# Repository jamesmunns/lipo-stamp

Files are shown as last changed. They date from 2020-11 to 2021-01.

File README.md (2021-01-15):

# LiPo Power Stamp

This is intended to be a small sized, general purpose LiPo charge controller with power path and a 3v3 regulator. Currently the targeted size is 0.7" by 0.7", or just under 18mm square. It is intended to be used with 3.7V nominal cells.

## Features

* TP4056 Charge Controller
    * 500mA charging current
    * Low voltage trickle charging
* Over/Under-voltage Protection
    * AP9101CK6 + FS8205
    * Disables cell on over/under charge
* Power Path
    * Provides power via USB when connected
    * 500mA max output (USB or Cell)
* Switchable 3v3 Regulator
    * Default off
    * 100mA+ output
* Resettable Polyfuse
    * For high current, direct battery applications (e.g. LEDs)
    * Max 2A continuous output

## Stamp v0.3.0

This is the current version of the board.

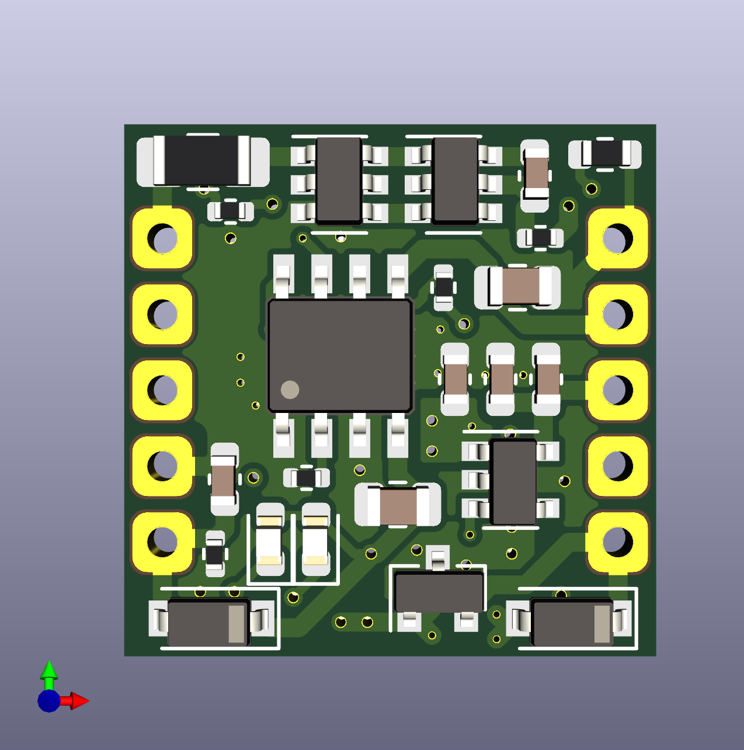
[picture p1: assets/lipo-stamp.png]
stamp render front

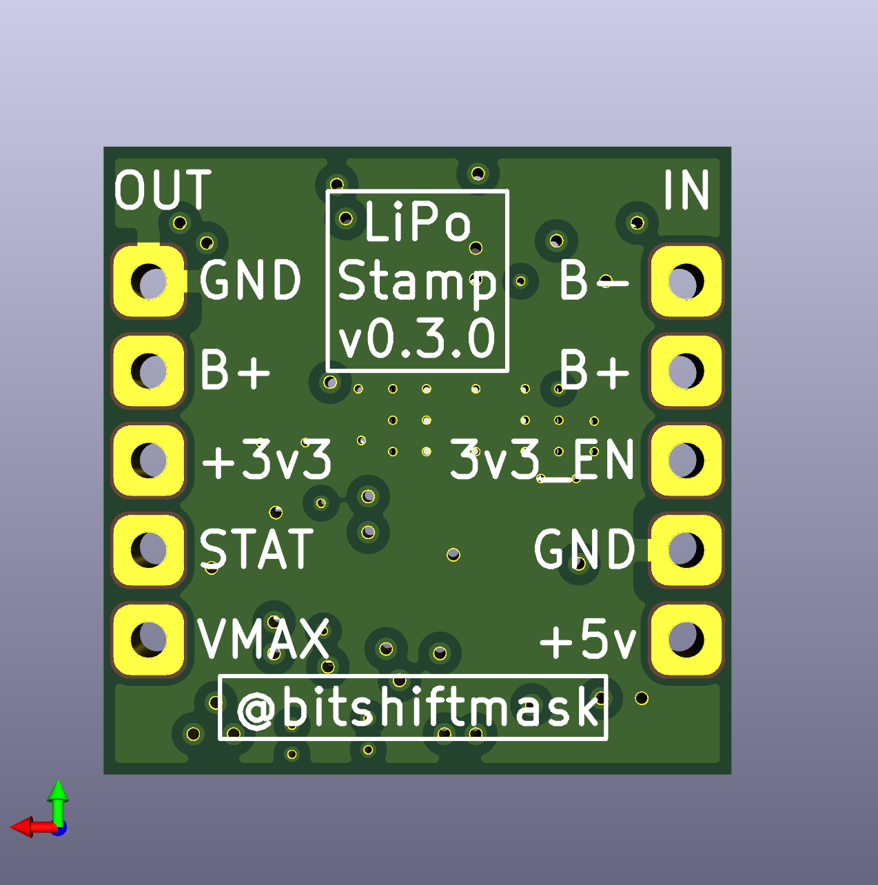
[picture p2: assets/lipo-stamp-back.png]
stamp render back


### Design Files

* [Schematic](./assets/stamp-schematic.pdf)
* [Layout](./assets/stamp-layout.pdf)

## Proto Version

The first version is a larger scale test board.

The [schematic](./assets/proto-schematic.pdf) is also available as PDF.

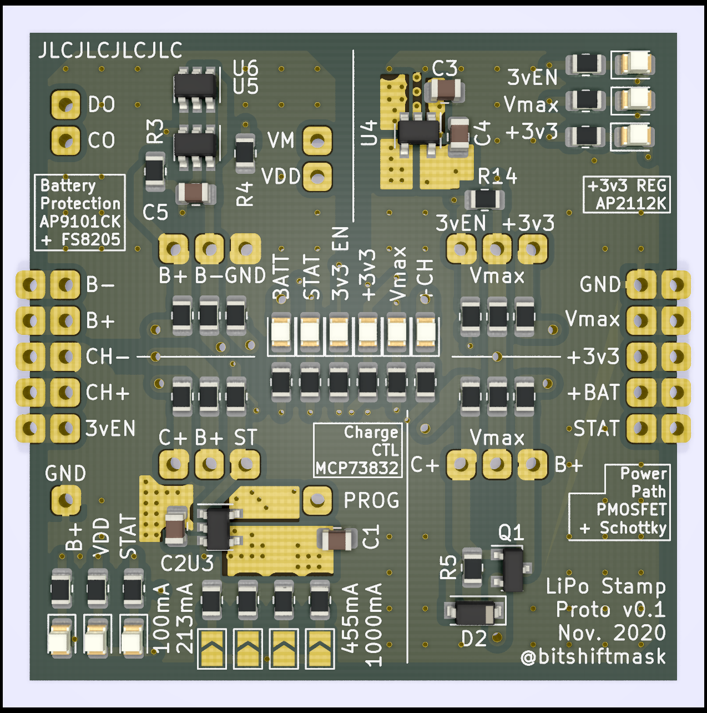
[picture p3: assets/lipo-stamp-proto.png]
test board


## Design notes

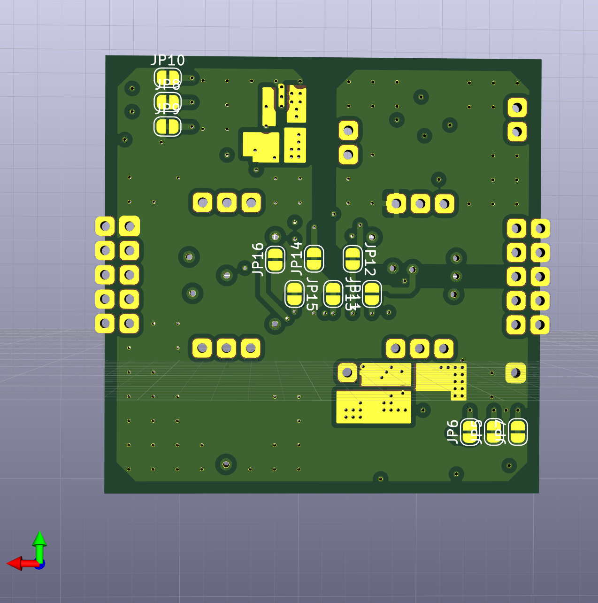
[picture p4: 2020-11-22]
assets/lipo-stamp-proto-back.png

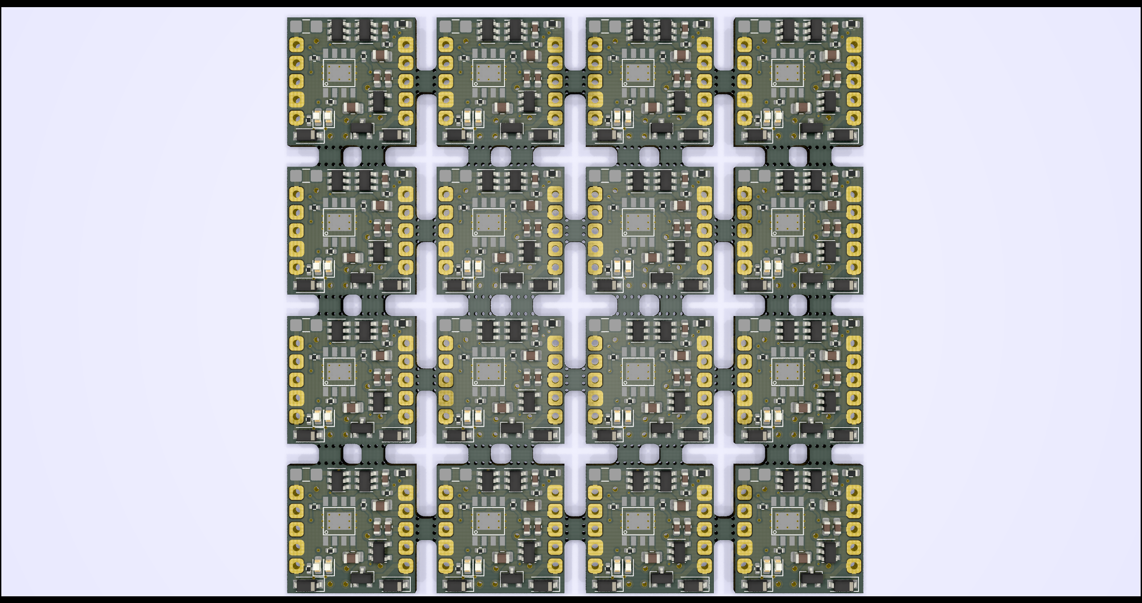
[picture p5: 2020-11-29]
assets/panel2.png

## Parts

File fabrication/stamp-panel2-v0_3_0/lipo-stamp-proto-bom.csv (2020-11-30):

Value | Designator | Footprint | LCSC Part Number
10uF | C1,C2 | C0805 | C15850
100nF | C5 | C0603 | C14663
1uF | C3,C4,C6,C7 | C0603 | C15849
GREEN | D1 | LED_0603 | C72043
RED | D2 | LED_0603 | C2286
B5819W | D3,D4 | SOD-123 | C8598
nSMD200 | F1 | F1206 | C70085
TP4056 | IC1 | SOP-8_3.9x4.9x1.27P | C16581
SI2301CDS-T1-GE3 | Q1 | SOT-23-3 | C10487
2.2K | R1 | R0402 | C25879
1K | R2,R3 | R0402 | C11702
100K | R4 | R0402 | C25741
330 | R5 | R0402 | C25104
2.7kOhm | R6 | R0603 | C13167
AP2112K-3.3 | U1 | SOT-25-5 | C51118
AP9101CK6 | U2 | SOT-23-6L | C151339
FS8205 | U3 | SOT-23-6L | C32254

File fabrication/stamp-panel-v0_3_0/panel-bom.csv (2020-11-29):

Id | Designator | Package | Quantity | Designation | Supplier and ref
1 | D1,D1,D1,D1,D1,D1,D1,D1,D1,D1,D1,D1,D1,D1,D1,D1 | LED_0603_1608Metric | 16 | GREEN
2 | D2,D2,D2,D2,D2,D2,D2,D2,D2,D2,D2,D2,D2,D2,D2,D2 | LED_0603_1608Metric | 16 | RED
3 | F1,F1,F1,F1,F1,F1,F1,F1,F1,F1,F1,F1,F1,F1,F1,F1 | Fuse_1206_3216Metric_Castellated | 16 | 2A Polyfuse
4 | IC1,IC1,IC1,IC1,IC1,IC1,IC1,IC1,IC1,IC1,IC1,IC1,IC1,IC1,IC1,IC1 | SOP-8 | 16 | TP4056
5 | Q1,Q1,Q1,Q1,Q1,Q1,Q1,Q1,Q1,Q1,Q1,Q1,Q1,Q1,Q1,Q1 | SOT-23 | 16 | SI2301CDS-T1-GE3
6 | R1,R1,R1,R1,R1,R1,R1,R1,R1,R1,R1,R1,R1,R1,R1,R1 | R_0402_1005Metric | 16 | 2.2K
7 | R2,R3,R2,R3,R2,R3,R2,R3,R2,R3,R2,R3,R2,R3,R2,R3,R2,R3,R2,R3,R2,R3,R2,R3,R2,R3,R2,R3,R2,R3,R2,R3 | R_0402_1005Metric | 32 | 1K
8 | R4,R4,R4,R4,R4,R4,R4,R4,R4,R4,R4,R4,R4,R4,R4,R4 | R_0402_1005Metric | 16 | 100K
9 | R5,R5,R5,R5,R5,R5,R5,R5,R5,R5,R5,R5,R5,R5,R5,R5 | R_0402_1005Metric | 16 | 330
10 | TP1,TP2,TP3,TP4,TP5,TP6,TP7,TP8,TP9,TP10,TP1,TP2,TP3,TP4,TP5,TP6,TP7,TP8,TP9,TP10,TP1,TP2,TP3,TP4,TP5,TP6,TP7,TP8,TP9,TP10,TP1,TP2,TP3,TP4,TP5,TP6,TP7,TP8,TP9,TP10,TP1,TP2,TP3,TP4,TP5,TP6,TP7,TP8,TP9,TP10,TP1,TP2,TP3,TP4,TP5,TP6,TP7,TP8,TP9,TP10,TP1,TP2,TP3,TP4,TP5,TP6,TP7,TP8,TP9,TP10,TP1,TP2,TP3,TP4,TP5,TP6,TP7,TP8,TP9,TP10,TP1,TP2,TP3,TP4,TP5,TP6,TP7,TP8,TP9,TP10,TP1,TP2,TP3,TP4,TP5,TP6,TP7,TP8,TP9,TP10,TP1,TP2,TP3,TP4,TP5,TP6,TP7,TP8,TP9,TP10,TP1,TP2,TP3,TP4,TP5,TP6,TP7,TP8,TP9,TP10,TP1,TP2,TP3,TP4,TP5,TP6,TP7,TP8,TP9,TP10,TP1,TP2,TP3,TP4,TP5,TP6,TP7,TP8,TP9,TP10,TP1,TP2,TP3,TP4,TP5,TP6,TP7,TP8,TP9,TP10,TP1,TP2,TP3,TP4,TP5,TP6,TP7,TP8,TP9,TP10 | castellated-2-pin | 160 | TestPoint
11 | U1,U1,U1,U1,U1,U1,U1,U1,U1,U1,U1,U1,U1,U1,U1,U1 | SOT-23-5 | 16 | AP2112K-3.3
12 | U2,U2,U2,U2,U2,U2,U2,U2,U2,U2,U2,U2,U2,U2,U2,U2 | SOT-23-6 | 16 | AP9101CK6
13 | U3,U3,U3,U3,U3,U3,U3,U3,U3,U3,U3,U3,U3,U3,U3,U3 | SOT-23-6 | 16 | FS8205
14 | D3,D4,D3,D4,D3,D4,D3,D4,D3,D4,D3,D4,D3,D4,D3,D4,D3,D4,D3,D4,D3,D4,D3,D4,D3,D4,D3,D4,D3,D4,D3,D4 | D_SOD-123 | 32 | D_Schottky
15 | C1,C2,C1,C2,C1,C2,C1,C2,C1,C2,C1,C2,C1,C2,C1,C2,C1,C2,C1,C2,C1,C2,C1,C2,C1,C2,C1,C2,C1,C2,C1,C2 | C_0805_2012Metric | 32 | 10uF
16 | C3,C4,C3,C4,C3,C4,C3,C4,C3,C4,C3,C4,C3,C4,C3,C4,C3,C4,C3,C4,C3,C4,C3,C4,C3,C4,C3,C4,C3,C4,C3,C4 | C_0603_1608Metric | 32 | 1uF
17 | C5,C5,C5,C5,C5,C5,C5,C5,C5,C5,C5,C5,C5,C5,C5,C5 | C_0603_1608Metric | 16 | 100nF
18 | R6,R6,R6,R6,R6,R6,R6,R6,R6,R6,R6,R6,R6,R6,R6,R6 | R_0603_1608Metric | 16 | 2.7kOhm

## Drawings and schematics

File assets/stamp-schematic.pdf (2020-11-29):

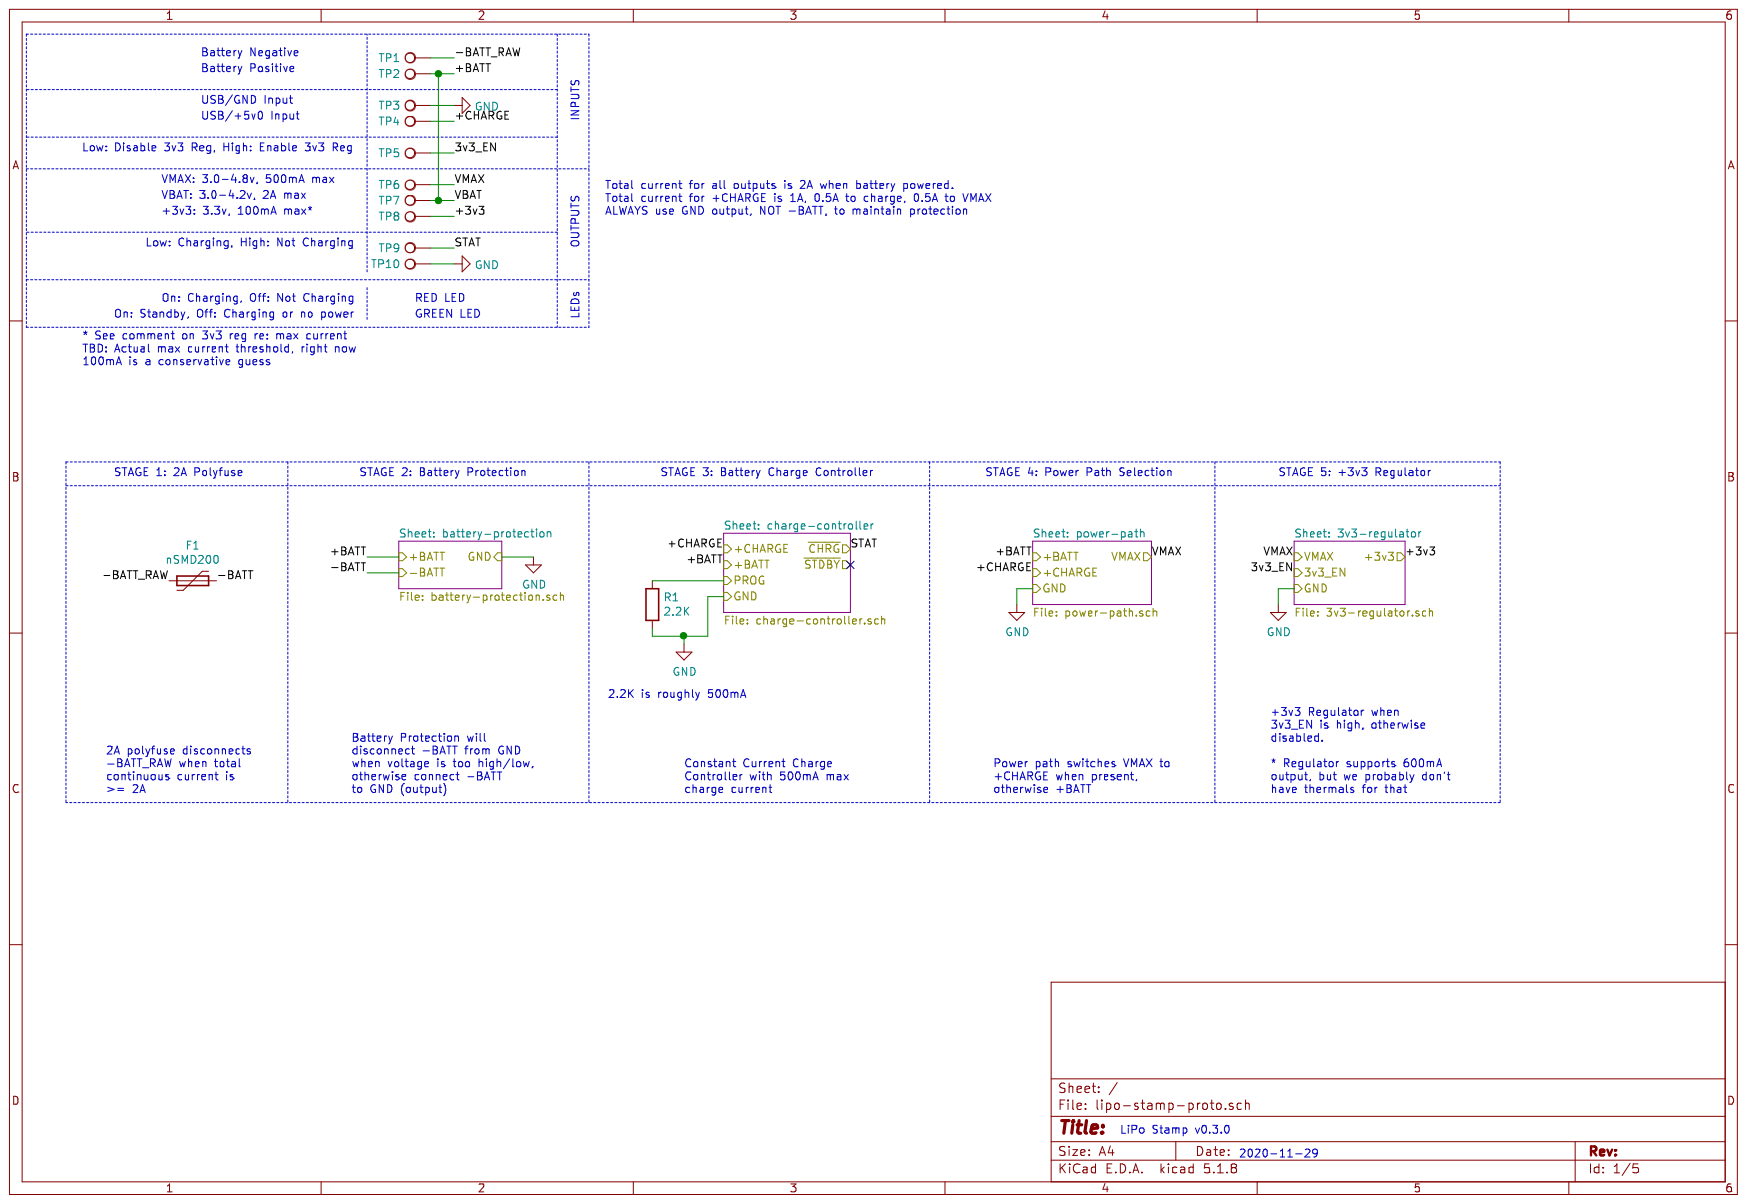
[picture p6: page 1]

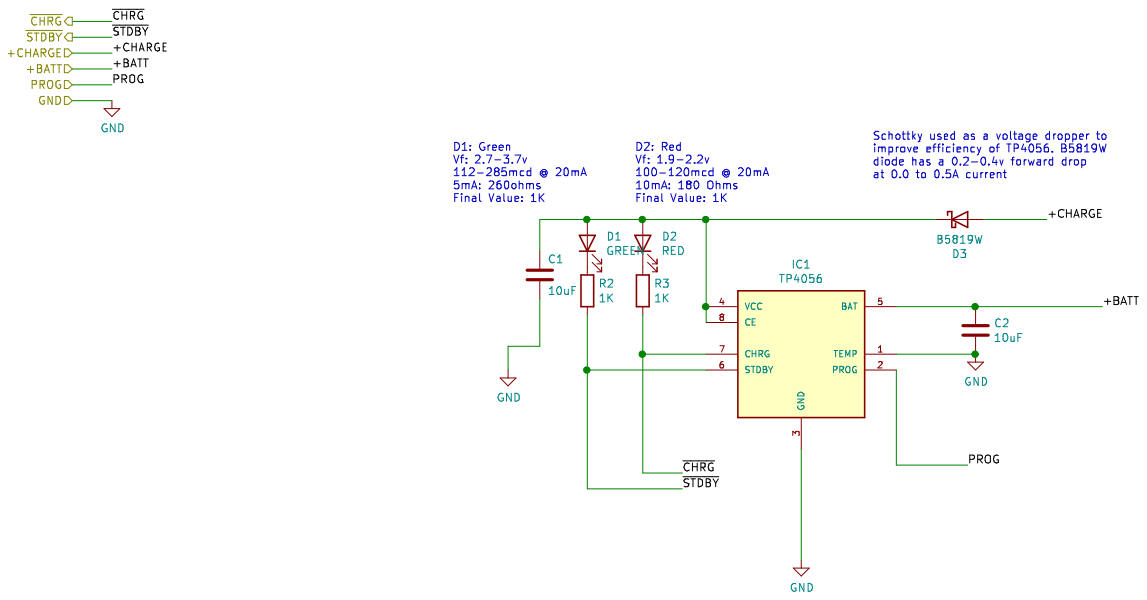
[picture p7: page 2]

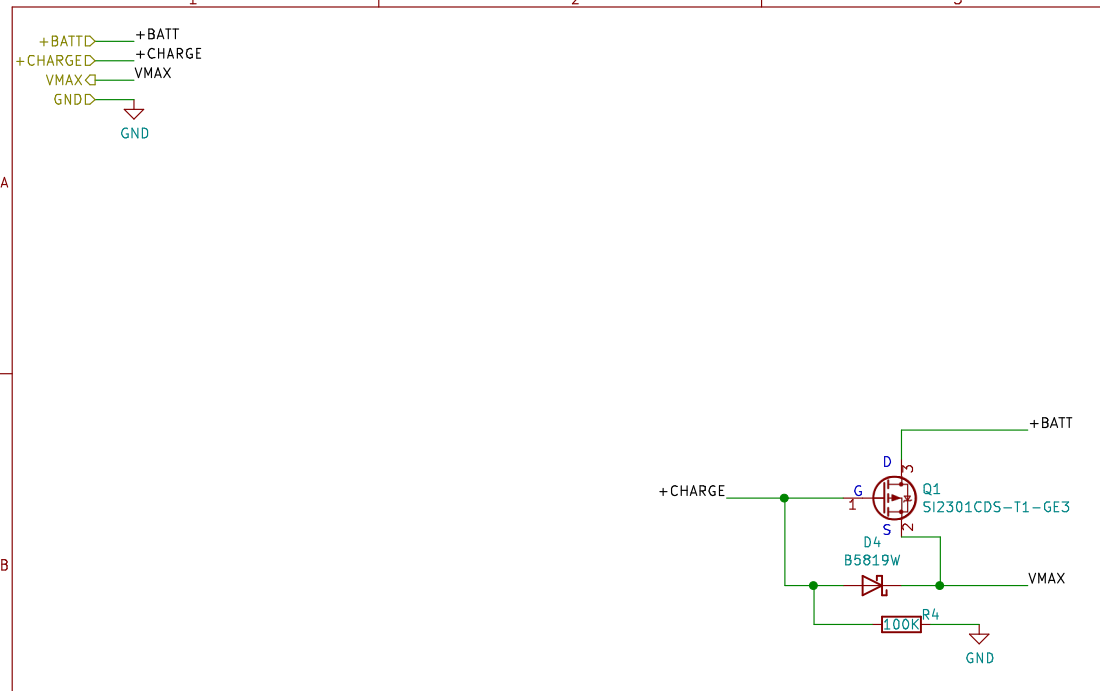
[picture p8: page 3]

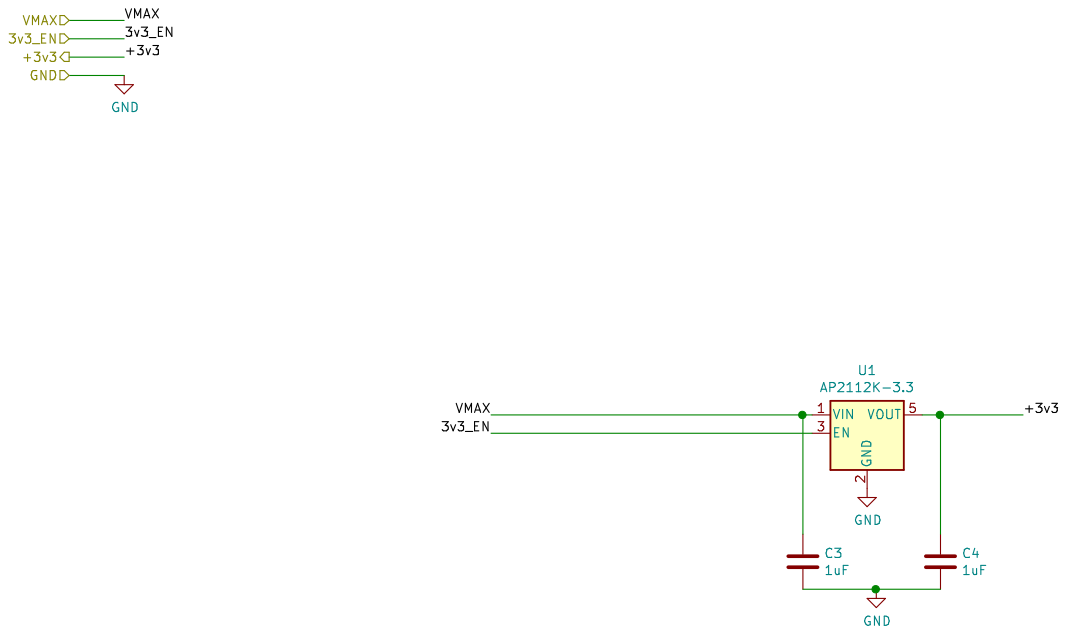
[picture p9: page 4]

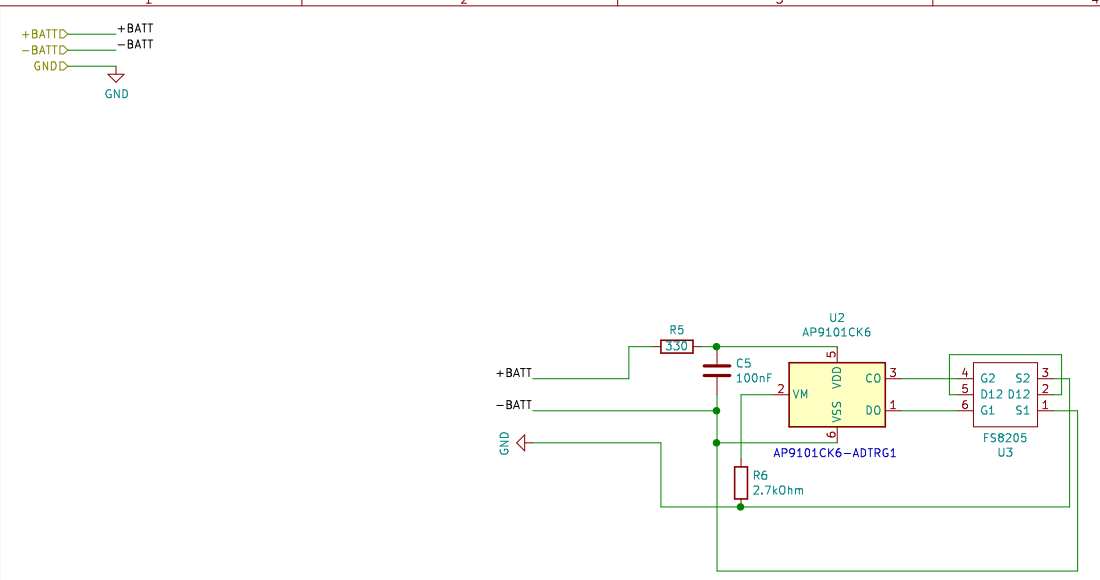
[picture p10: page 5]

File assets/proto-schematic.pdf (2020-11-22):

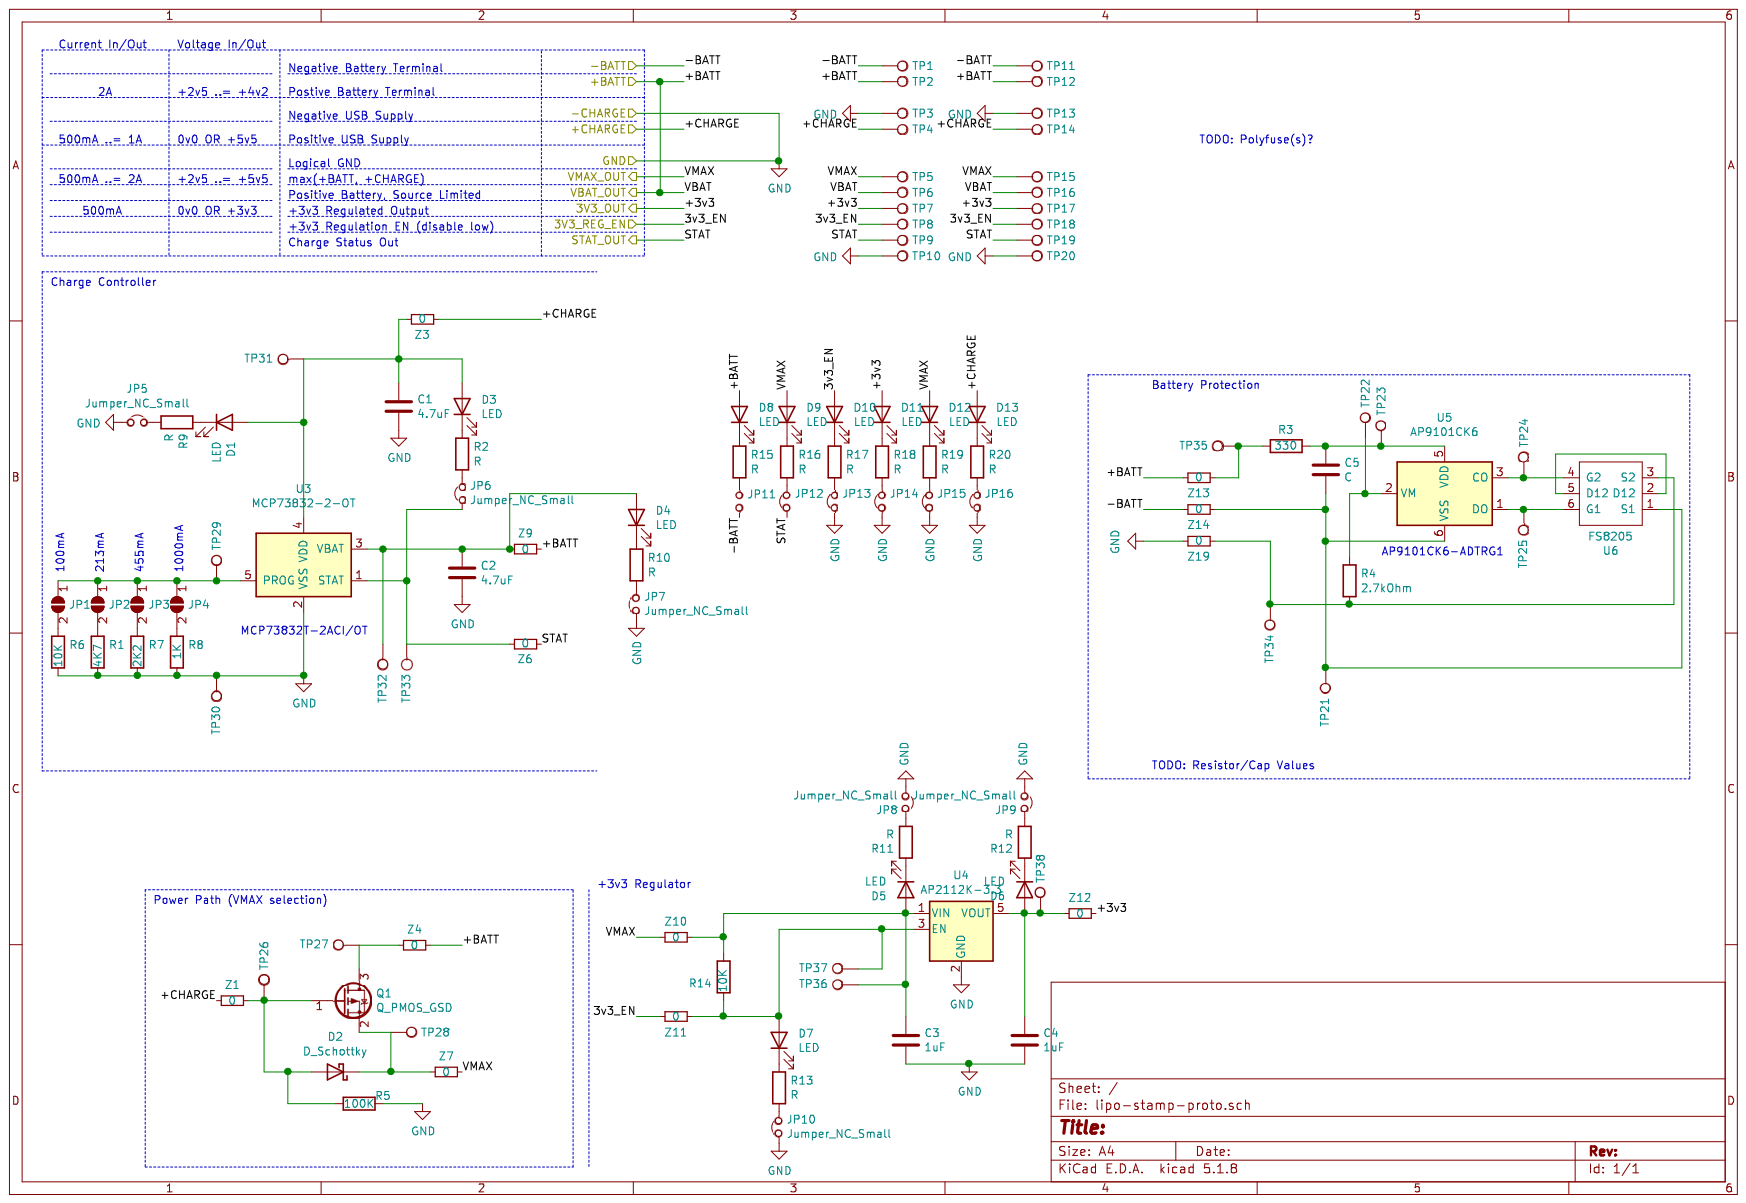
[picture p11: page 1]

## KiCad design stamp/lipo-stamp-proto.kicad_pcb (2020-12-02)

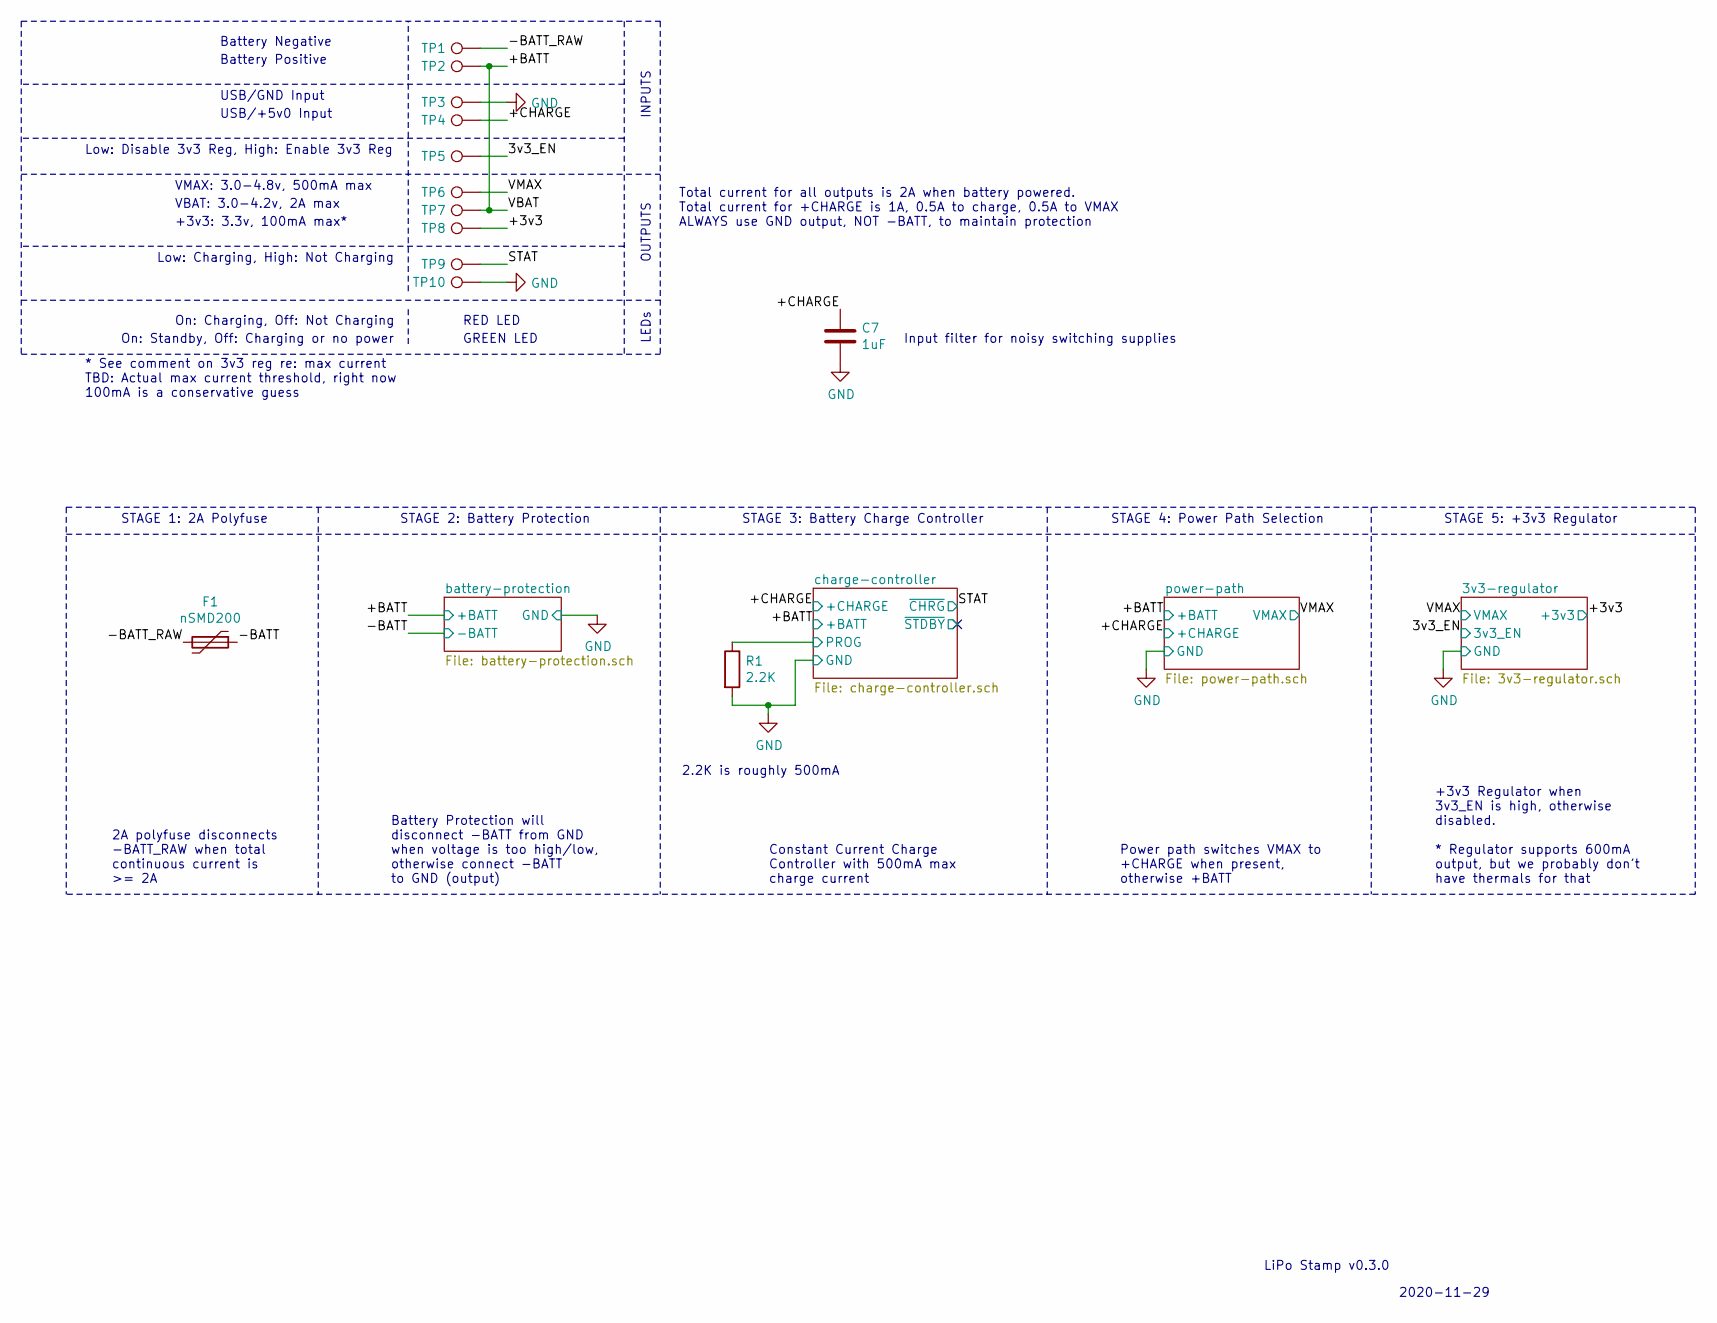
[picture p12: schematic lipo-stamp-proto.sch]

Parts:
C7: 1uF; C_0603_1608Metric
F1: nSMD200; Fuse_1206_3216Metric_Castellated
R1: 2.2K; R_0402_1005Metric
TP1, TP2, TP3, TP4, TP5, TP6, TP7, TP8, TP9, TP10: TestPoint; castellated-2-pin

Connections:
/3v3_EN: TP5.1; also elsewhere on the board
/+3v3: TP8.1; also elsewhere on the board
/+BATT: TP2.1, TP7.1; also elsewhere on the board
/+CHARGE: C7.1, TP4.1; also elsewhere on the board
/-BATT: F1.1; also elsewhere on the board
/-BATT_RAW: F1.2, TP1.1
/STAT: TP9.1; also elsewhere on the board
/VMAX: TP6.1; also elsewhere on the board
/charge-controller/PROG: R1.1; also elsewhere on the board
GND: C7.2, R1.2, TP3.1, TP10.1; also elsewhere on the board

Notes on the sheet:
2.2K is roughly 500mA
VMAX: 3.0-4.8v, 500mA max
VBAT: 3.0-4.2v, 2A max
+3v3: 3.3v, 100mA max*
Low: Charging, High: Not Charging
Low: Disable 3v3 Reg, High: Enable 3v3 Reg
USB/+5v0 Input
USB/GND Input
Battery Positive
Battery Negative
INPUTS
OUTPUTS
Total current for all outputs is 2A when battery powered. Total current for +CHARGE is 1A, 0.5A to charge, 0.5A to VMAX ALWAYS use GND output, NOT -BATT, to maintain protection
LiPo Stamp v0.3.0
2020-11-29
RED LED
GREEN LED
On: Charging, Off: Not Charging
On: Standby, Off: Charging or no power
LEDs
2A polyfuse disconnects -BATT_RAW when total continuous current is >= 2A
Battery Protection will disconnect -BATT from GND when voltage is too high/low, otherwise connect -BATT to GND (output)
Constant Current Charge Controller with 500mA max charge current
Power path switches VMAX to +CHARGE when present, otherwise +BATT
+3v3 Regulator when 3v3_EN is high, otherwise disabled. * Regulator supports 600mA output, but we probably don't have thermals for that
* See comment on 3v3 reg re: max current TBD: Actual max current threshold, right now 100mA is a conservative guess
STAGE 1: 2A Polyfuse
STAGE 2: Battery Protection
STAGE 3: Battery Charge Controller
STAGE 4: Power Path Selection
STAGE 5: +3v3 Regulator
Input filter for noisy switching supplies

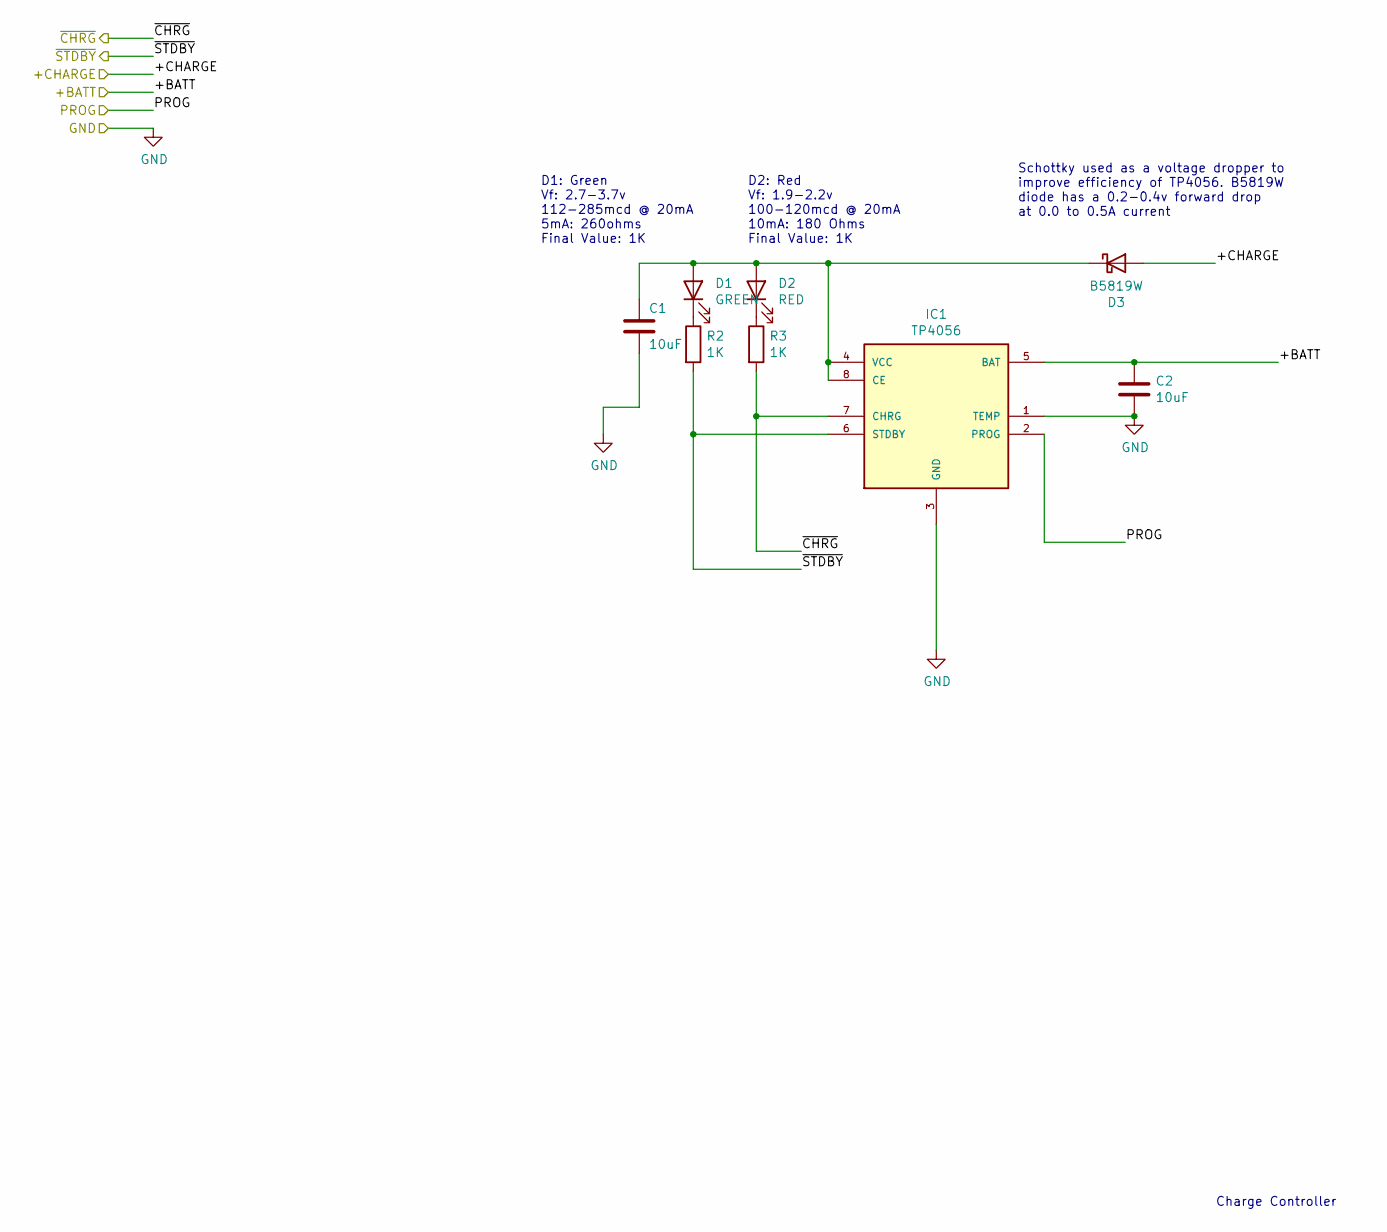
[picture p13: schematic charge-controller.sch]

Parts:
C1, C2: 10uF; C_0805_2012Metric
D1: GREEN; LED_0603_1608Metric
D2: RED; LED_0603_1608Metric
D3: B5819W; D_SOD-123
IC1: TP4056; SOP-8
R2, R3: 1K; R_0402_1005Metric

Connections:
/+BATT: C2.1, IC1.5 (BAT); also elsewhere on the board
/+CHARGE: D3.2 (A); also elsewhere on the board
/STAT: IC1.7 (CHRG), R3.2; also elsewhere on the board
/charge-controller/PROG: IC1.2 (PROG); also elsewhere on the board
/charge-controller/~STDBY: IC1.6 (STDBY), R2.2
GND: C1.2, C2.2, IC1.1 (TEMP), IC1.3 (GND); also elsewhere on the board
unnamed: C1.1, D1.2 (A), D2.2 (A), D3.1 (K), IC1.4 (VCC), IC1.8 (CE)
unnamed: D1.1 (K), R2.1
unnamed: D2.1 (K), R3.1

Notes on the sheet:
Charge Controller
Schottky used as a voltage dropper to improve efficiency of TP4056. B5819W diode has a 0.2-0.4v forward drop at 0.0 to 0.5A current
D1: Green Vf: 2.7-3.7v 112-285mcd @ 20mA 5mA: 260ohms Final Value: 1K
D2: Red Vf: 1.9-2.2v 100-120mcd @ 20mA 10mA: 180 Ohms Final Value: 1K

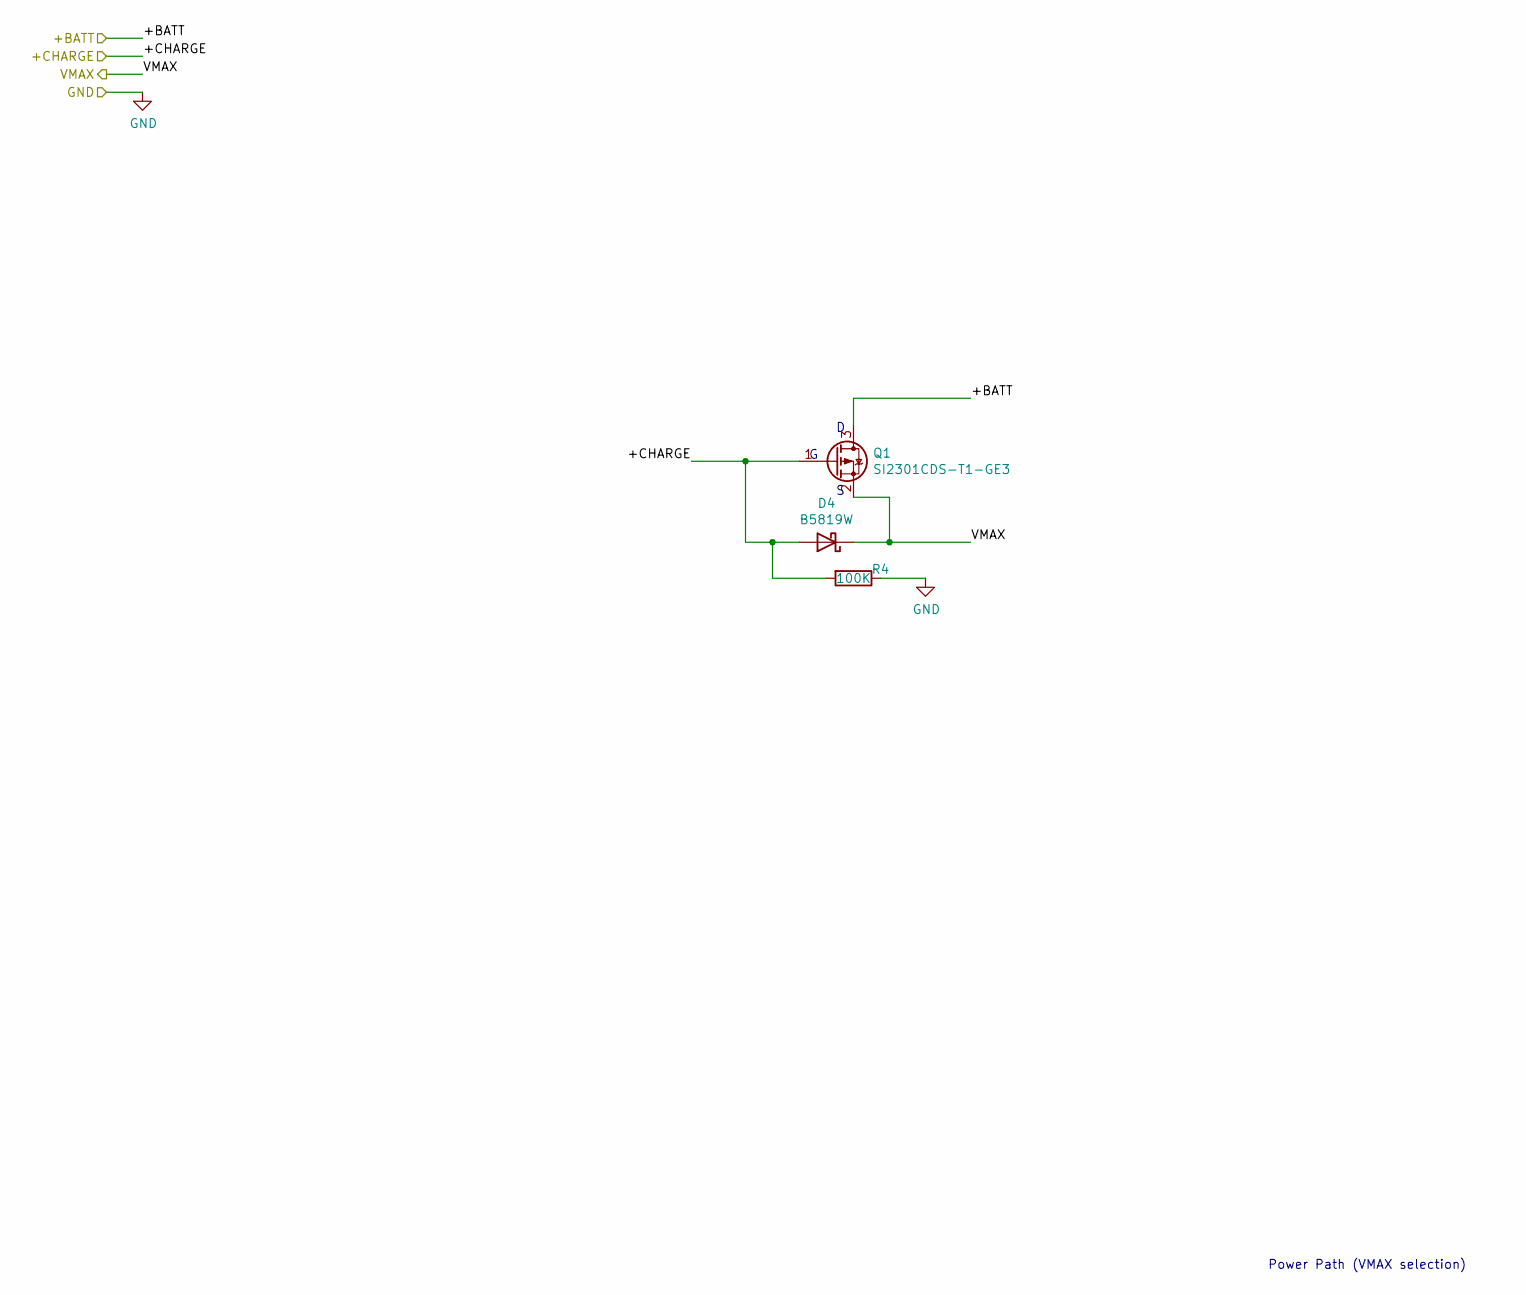
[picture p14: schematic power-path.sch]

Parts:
D4: B5819W; D_SOD-123
Q1: SI2301CDS-T1-GE3; SOT-23
R4: 100K; R_0402_1005Metric

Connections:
/+BATT: Q1.3 (D); also elsewhere on the board
/+CHARGE: D4.2 (A), Q1.1 (G), R4.2; also elsewhere on the board
/VMAX: D4.1 (K), Q1.2 (S); also elsewhere on the board
GND: R4.1; also elsewhere on the board

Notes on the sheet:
Power Path (VMAX selection)

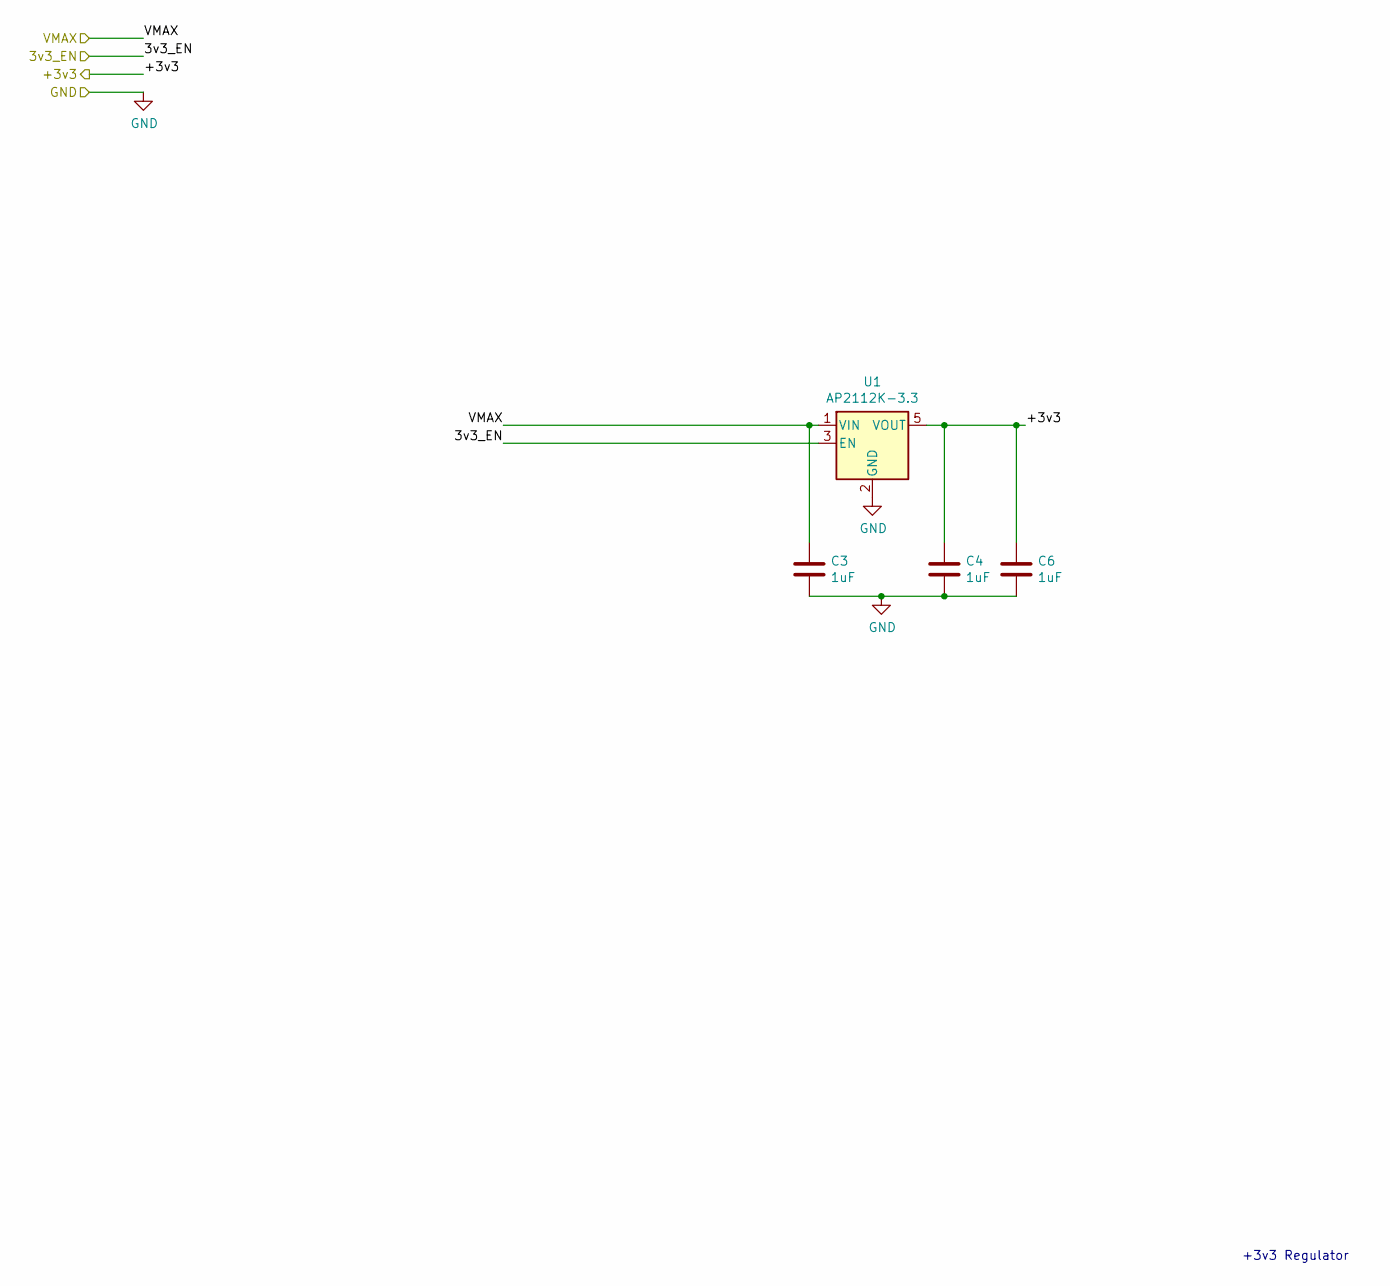
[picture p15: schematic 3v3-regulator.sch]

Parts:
C3, C4, C6: 1uF; C_0603_1608Metric
U1: AP2112K-3.3; SOT-23-5

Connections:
/3v3_EN: U1.3 (EN); also elsewhere on the board
/+3v3: C4.1, C6.1, U1.5 (VOUT); also elsewhere on the board
/VMAX: C3.1, U1.1 (VIN); also elsewhere on the board
GND: C3.2, C4.2, C6.2, U1.2 (GND); also elsewhere on the board

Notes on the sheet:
+3v3 Regulator

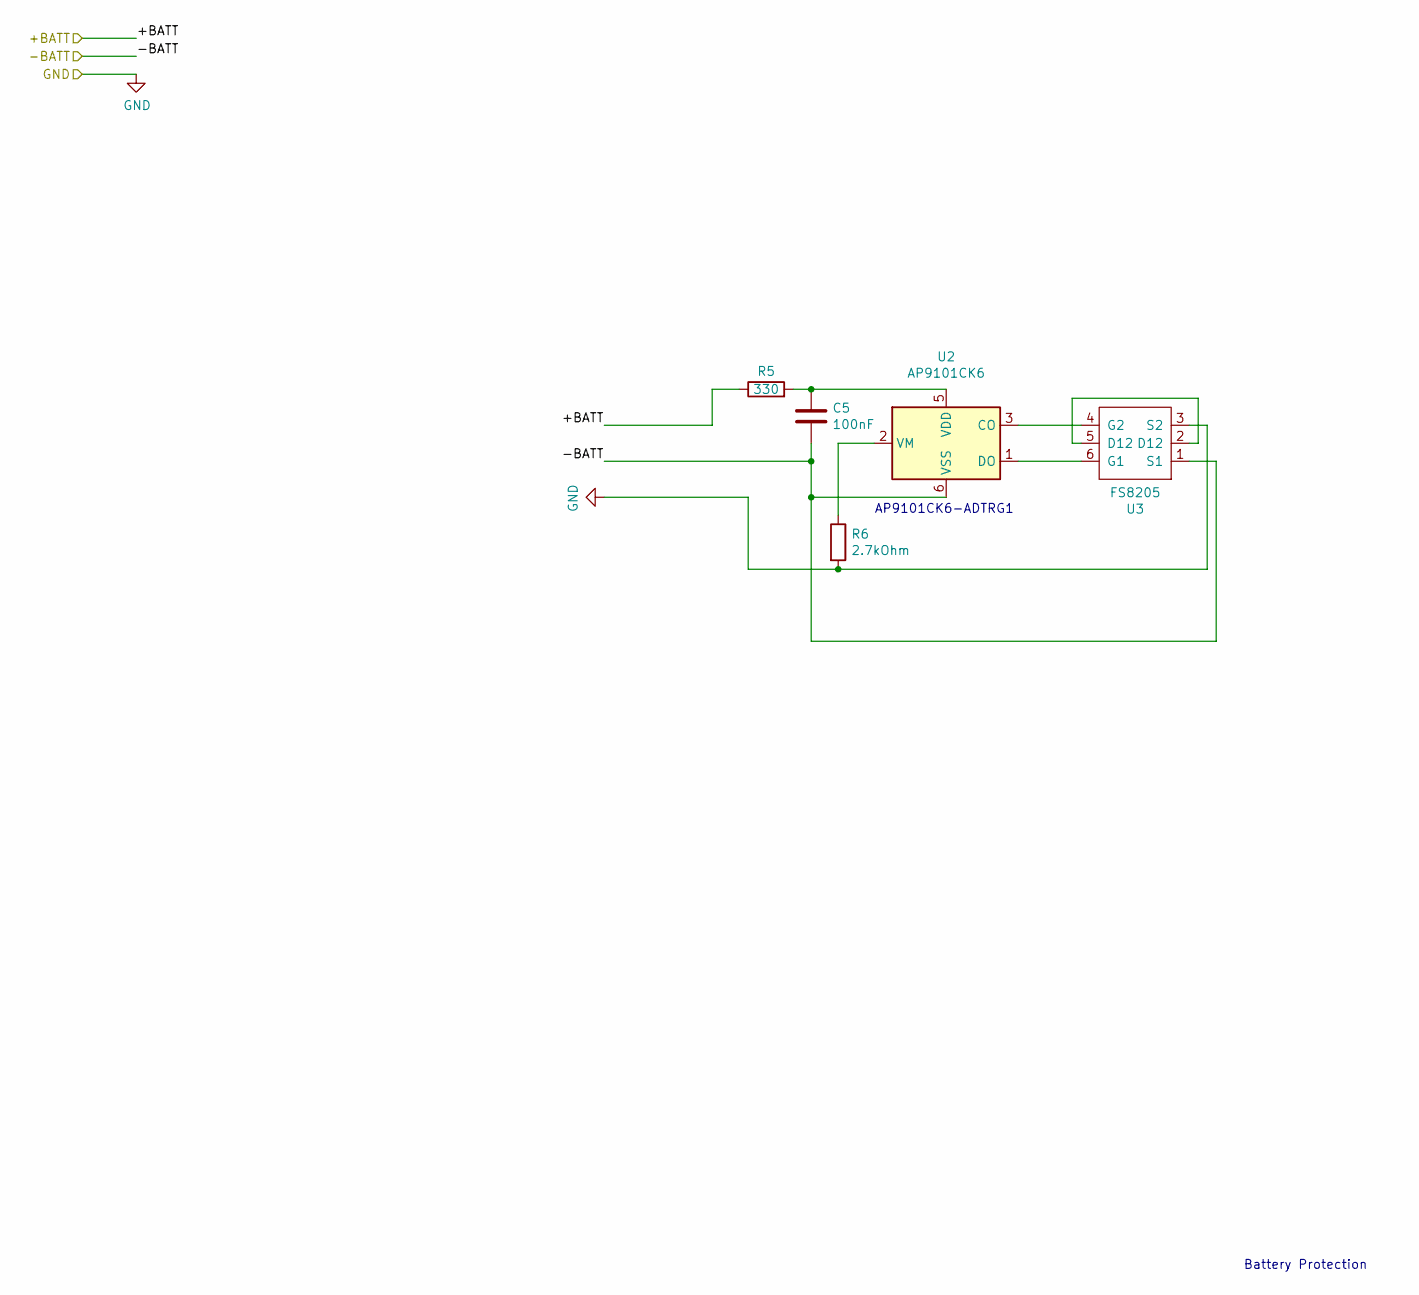
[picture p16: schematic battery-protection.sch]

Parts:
C5: 100nF; C_0603_1608Metric
R5: 330; R_0402_1005Metric
R6: 2.7kOhm; R_0603_1608Metric
U2: AP9101CK6; SOT-23-6
U3: FS8205; SOT-23-6

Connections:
/+BATT: R5.1; also elsewhere on the board
/-BATT: C5.2, U2.6 (VSS), U3.1 (S1); also elsewhere on the board
GND: R6.2, U3.3 (S2); also elsewhere on the board
unnamed: C5.1, R5.2, U2.5 (VDD)
unnamed: R6.1, U2.2 (VM)
unnamed: U2.1 (DO), U3.6 (G1)
unnamed: U2.3 (CO), U3.4 (G2)
unnamed: U3.2 (D12), U3.5 (D12)

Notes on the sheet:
AP9101CK6-ADTRG1
Battery Protection

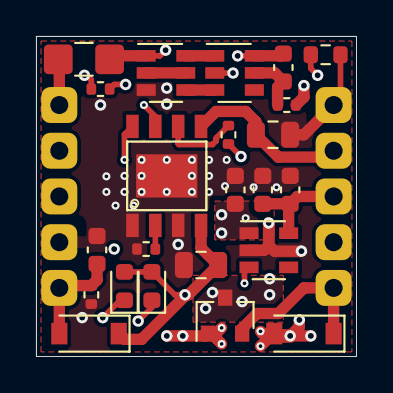
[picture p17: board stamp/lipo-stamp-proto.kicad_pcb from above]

Board: 4 copper layers, 17.8 x 17.8 mm, 33 parts (0 on the bottom side), 19 nets.

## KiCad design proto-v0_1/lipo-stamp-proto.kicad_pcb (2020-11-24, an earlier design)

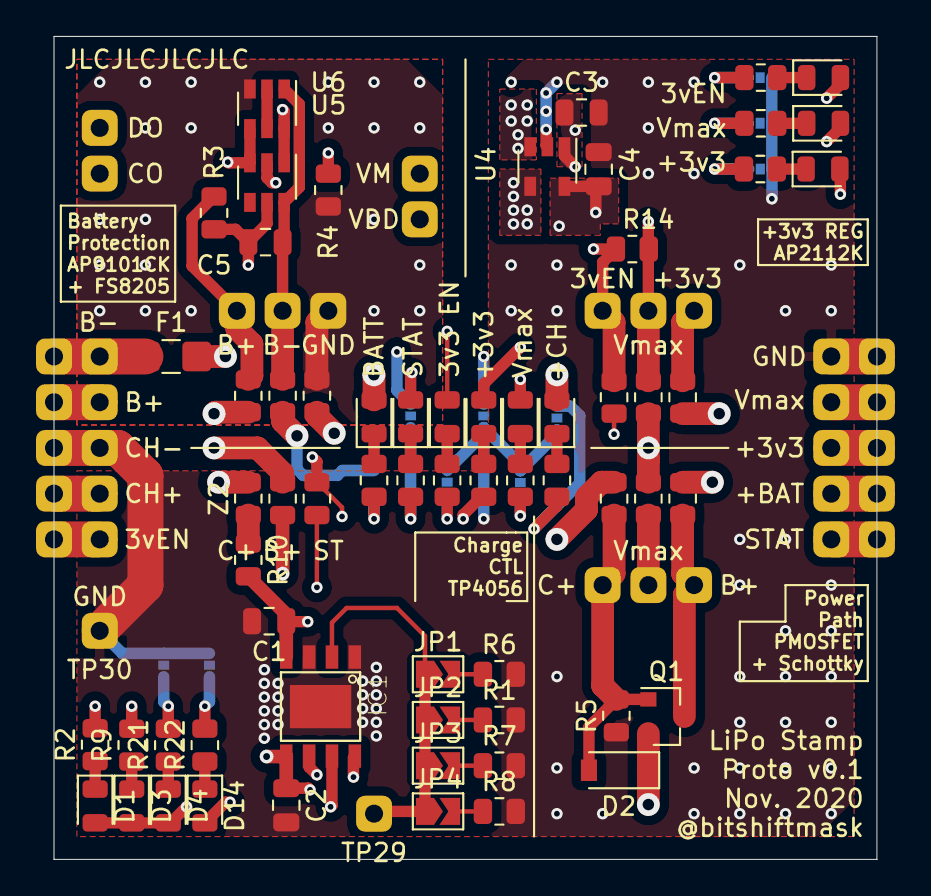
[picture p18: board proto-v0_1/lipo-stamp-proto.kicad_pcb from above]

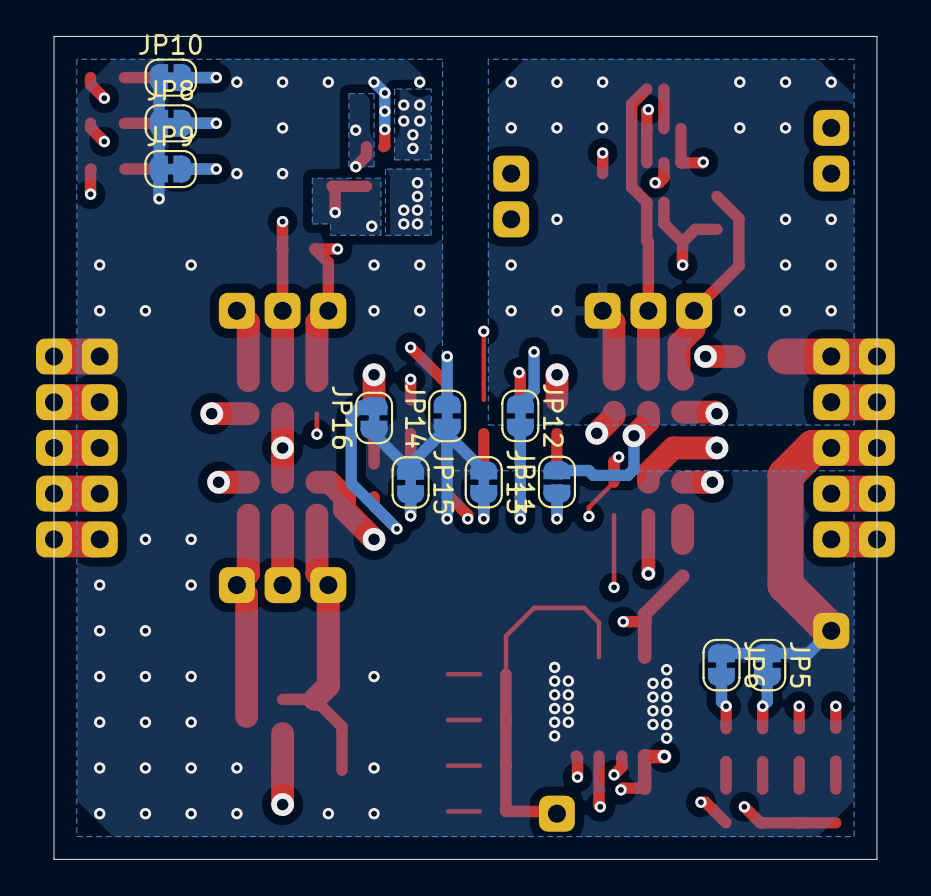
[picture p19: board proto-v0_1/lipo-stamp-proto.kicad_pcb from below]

Board: 4 copper layers, 45.7 x 45.7 mm, 109 parts (11 on the bottom side), 57 nets.

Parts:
C1, C2: 10uF; C_0805_2012Metric
C3, C4: 1uF; C_0805_2012Metric
C5: C; C_0805_2012Metric
D1, D3, D4, D5, D6, D7, D8, D9, D10, D11, D12, D13, D14: LED; LED_0805_2012Metric
D2: D_Schottky; D_SOD-123
F1: Polyfuse; Fuse_1206_3216Metric_Castellated
IC1: TP4056; SOP-8
JP1, JP2, JP3, JP4: SolderJumper_2_Open; SolderJumper-2_P1.3mm_Open_TrianglePad1.0x1.5mm
JP5, JP6, JP8, JP9, JP10, JP12, JP13, JP14, JP15, JP16: Jumper_NC_Small; SolderJumper-2_P1.3mm_Bridged_RoundedPad1.0x1.5mm
JP11: Jumper_NO_Small; SolderJumper-2_P1.3mm_Open_RoundedPad1.0x1.5mm
Q1: Q_PMOS_GSD; SOT-23
R1: 4K7; R_0805_2012Metric
R2, R9, R11, R12, R13, R15, R16, R17, R18, R19, R20, R21, R22: R; R_0805_2012Metric
R3: 330; R_0805_2012Metric
R4: 2.7kOhm; R_0805_2012Metric
R5: 100K; R_0805_2012Metric
R6, R14: 10K; R_0805_2012Metric
R7: 2K2; R_0805_2012Metric
R8: 1K2; R_0805_2012Metric
R10: 0.4; R_0805_2012Metric
TP1, TP2, TP3, TP4, TP5, TP6, TP7, TP8, TP9, TP10, TP11, TP12, TP13, TP14, TP15, TP16, TP17, TP18, TP19, TP20, TP21, TP22, TP23, TP24, TP25, TP26, TP27, TP28, TP29, TP30, TP34, TP35, TP36, TP37, TP38: TestPoint; castellated-2-pin
U4: AP2112K-3.3; SOT-23-5
U5: AP9101CK6; SOT-23-6
U6: FS8205; SOT-23-6
Z1, Z2, Z4, Z6, Z7, Z9, Z10, Z11, Z12, Z13, Z14, Z19: 0; R_0805_2012Metric

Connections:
/3V3_OUT: D11.2, TP7.1, TP17.1, Z12.1
/3V3_REG_EN: D10.2, TP8.1, TP18.1, Z11.2
/+BATT: D8.2, TP2.1, TP6.1, TP12.1, TP16.1, Z4.1, Z9.1, Z13.1
/+CHARGE: D13.2, TP4.1, TP14.1, Z1.2, Z2.2
/-BATT: F1.1, JP11.2, Z14.1
/-BATT_RAW: F1.2, TP1.1, TP11.1
/STAT_OUT: JP12.1, TP9.1, TP19.1, Z6.2
/VMAX_OUT: D9.2, D12.2, TP5.1, TP15.1, Z7.1, Z10.2
GND: C1.2, C2.2, C3.2, C4.2, IC1.1, IC1.3, JP5.1, JP6.1, JP8.1, JP9.1, JP10.1, JP13.1, JP14.1, JP15.1, JP16.1, R1.2, R5.1, R6.2, R7.2, R8.2, TP3.1, TP10.1, TP13.1, TP20.1, TP30.1, U4.2, Z19.1
unnamed: C1.1, D1.2, D3.2, D4.2, IC1.4, IC1.8, R10.2
unnamed: C2.1, D14.2, IC1.5, Z9.2
unnamed: C3.1, D5.2, R14.2, TP36.1, U4.1, Z10.1
unnamed: C4.1, D6.2, TP38.1, U4.5, Z12.2
unnamed: C5.1, R3.2, TP23.1, U5.5
unnamed: C5.2, TP21.1, U5.6, U6.1, Z14.2
unnamed: D1.1, R2.1
unnamed: D2.1, Q1.2, TP28.1, Z7.2
unnamed: D2.2, Q1.1, R5.2, TP26.1, Z1.1
unnamed: D3.1, R9.1
unnamed: D4.1, R21.1
unnamed: D5.1, R11.1
unnamed: D6.1, R12.1
unnamed: D7.1, R13.1
unnamed: D7.2, R14.1, TP37.1, U4.3, Z11.1
unnamed: D8.1, R15.1
unnamed: D9.1, R16.1
unnamed: D10.1, R17.1
unnamed: D11.1, R18.1
unnamed: D12.1, R19.1
unnamed: D13.1, R20.1
unnamed: D14.1, R22.1
unnamed: IC1.2, JP1.1, JP2.1, JP3.1, JP4.1, TP29.1
unnamed: IC1.6, R2.2
unnamed: IC1.7, R9.2, Z6.1
unnamed: JP1.2, R6.1
unnamed: JP2.2, R1.1
unnamed: JP3.2, R7.1
unnamed: JP4.2, R8.1
unnamed: JP5.2, R21.2
unnamed: JP6.2, R22.2
unnamed: JP8.2, R11.2
unnamed: JP9.2, R12.2
unnamed: JP10.2, R13.2
unnamed: JP11.1, R15.2
unnamed: JP12.2, R16.2
unnamed: JP13.2, R17.2
unnamed: JP14.2, R18.2
unnamed: JP15.2, R19.2
unnamed: JP16.2, R20.2
unnamed: Q1.3, TP27.1, Z4.2
unnamed: R3.1, TP35.1, Z13.2
unnamed: R4.1, TP22.1, U5.2
unnamed: R4.2, TP34.1, U6.3, Z19.2
unnamed: R10.1, Z2.1
unnamed: TP24.1, U5.3, U6.4
unnamed: TP25.1, U5.1, U6.6
unnamed: U6.2, U6.5

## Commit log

2020-11-21 Import from other project
    [lipo-stamp-proto.sch]
2020-11-21 Initial import
    [lipo-stamp-proto.kicad_pcb, lipo-stamp-proto.sch]
2020-11-22 Going to start routing
    [lipo-stamp-proto.kicad_pcb, lipo-stamp-proto.sch]
2020-11-22 Passes DRC now
    [lipo-stamp-proto.kicad_pcb]
2020-11-22 Almost done, just needs back silkscreen
    [lipo-stamp-proto.kicad_pcb, lipo-stamp-proto.sch]
2020-11-22 Add schematic
2020-11-22 Add 2A polyfuse
    [lipo-stamp-proto.kicad_pcb, lipo-stamp-proto.sch]
2020-11-24 Polyfuse, pre-4056
    [lipo-stamp-proto.kicad_pcb]
2020-11-24 Rerouted TP4056, considering redoing
    [lipo-stamp-proto.kicad_pcb, lipo-stamp-proto.sch]
2020-11-29 Move silkscreen layers
    [lipo-stamp-proto.kicad_pcb]
2020-11-29 Add fabrication outputs, not jlc corrected yet
    [lipo-stamp-proto-B_Cu.gbr, lipo-stamp-proto-B_Mask.gbr, lipo-stamp-proto-B_Paste.gbr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]
2020-11-29 Update components, regenerate output
    [battery-protection.sch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]
2020-11-29 Add panelization
    [panel-B_CrtYd.gbr, panel-B_Cu.gbr, panel-B_Fab.gbr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]
2020-11-29 Add panelize script
    [lipo-stamp-proto.kicad_pcb]
2020-11-29 Remove accidental gerber output
    [panel-B_CrtYd.gbr, panel-B_Cu.gbr, panel-B_Fab.gbr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]
2020-11-29 Update exports/screenshots
    [charge-controller.sch, lipo-stamp-proto.sch, power-path.sch]
2020-11-29 Update render
    [lipo-stamp-proto.kicad_pcb]
2020-11-30 Address comments from Henrik
    [lipo-stamp-proto.kicad_pcb]
2020-11-30 Update panel fab
    [panel2-B_CrtYd.gbr, panel2-B_Cu.gbr, panel2-B_Fab.gbr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]
2020-11-30 Remove dead trace, increase return path via, add thermal spokes for ground
    [lipo-stamp-proto.kicad_pcb]
2020-11-30 Rework return path a bit more
    [lipo-stamp-proto.kicad_pcb]
2020-11-30 Update exports
    [lipo-stamp-proto.kicad_pcb]
2020-11-30 Break up big vias, use zones in inner layers for wider capacity
    [lipo-stamp-proto.kicad_pcb]
2020-11-30 Add more filter caps
    [3v3-regulator.sch, lipo-stamp-proto.kicad_pcb, lipo-stamp-proto.sch]
2020-11-30 Ordered on 2020-11-30. v0.3.0 release.
    [lipo-stamp-proto-B_CrtYd.gbr, lipo-stamp-proto-B_Cu.gbr, lipo-stamp-proto-B_Fab.gbr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]
2020-12-02 Update images
    [lipo-stamp-proto-bom.csv, lipo-stamp-proto.kicad_pcb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]
2021-01-14 Changed Battery to Cell and some other semantics
    Read the wiki (https://www.reddit.com/r/AskElectronics/wiki/batteries) of /r/batteries to learn more about batteries.
